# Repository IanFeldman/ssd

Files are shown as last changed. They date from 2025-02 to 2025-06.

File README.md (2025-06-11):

# ssd
2025 Cal Poly EE/CPE senior project exploring nonvolatile flash storage. Includes a [prototype design](#nor-prototype-2) using an 8051 and small NOR flash IC and the [final design](#nand-final) with a modern Atmel microcontroller and multiple high-density NAND flash ICs on a custom PCB.

## nand-final
2Gib NAND flash memory board with virtual serial interface over USB. Supports default and RAID 1 configurations.

### Firmware Build and Flash Instructions (Linux)
```sh
# Install dependencies
sudo apt install gcc-avr avr-libc avrdude make

# Clone this repo
git clone https://github.com/IanFeldman/ssd.git
cd ssd/nand-final/firmware

# Burn fuses (first time only)
make fuses

# Compile and flash firmware using ISP
# (edit makefile as needed)
make [UART=1] [RAID=1] # Optionally enable UART debugging or RAID 1
make flash
```

UART debugging interferes with some NAND chip control lines. Enable it at your own risk.\
RAID is performed across all 4 chips, so it decreases the address space fourfold.

### Usage:
Plug PCB into PC USB port and open a terminal with:\
```screen /dev/[path-to-usb-device] -b 9600```

### Commands:
<table>

<tr>
<td>Command</td>
<td>Usage</td>
<td>Function</td>
</tr>
<tr>
<td>Help</td>
<td>
  
```help```
</td>
<td>Displays device info and a list of commands.</td>
</tr>
<tr>
<td>Read</td>
<td>
  
```read 0x[row] 0x[column] [size]```
</td>
<td>Reads [size] bytes from memory.<br>A device will not read across a page boundary.</td>
</tr>
<tr>
<td>Write</td>
<td>
  
```write 0x[row] 0x[column] 0x[data]```
</td>
<td>Writes a single byte [data] to memory.</td>
</tr>
<tr>
<td>Erase</td>
<td>
  
```erase 0x[row]```
</td>
<td>Erases a block from memory.</td>
</tr>
</table>

Note:
- ```[row]``` is three bytes and represents a page address. Max value: 0x0FFFFF (0x040000 with RAID enabled).
- ```[column]``` is two bytes and represents a page offset in bytes. Max value: 0x07FF.
- ```[data]``` is one byte.
- ```[size]``` is a decimal unsigned integer.

## nor-prototype-2
Prototype breadboard 512kB flash memory storage device. Interface over UART at 9600 baud. Compile with SDCC and program with avrdude. See hardware schematic for hardware details.

### Firmware Build and Flash Instructions (Linux)
```sh
# Install dependencies
sudo apt install sdcc

# Clone this repo
git clone https://github.com/IanFeldman/ssd.git
cd ssd/nor-prototype-2/firmware

# Compile and flash firmware using ISP
make
./program.sh
```

### Usage:
Connect a serial cable to ```RXD``` and ```TXD``` on the microcontroller. Open a terminal with:\
```screen /dev/[path-to-serial-cable] -b 9600```

### Commands:
- Read an address ```r[address]```
- Erase an address ```e[address]```
- Program an address ```p[address][data]```

Where:
- ```[address]``` is 3 hex bytes
- ```[data]``` is one hex byte

## nor-prototype-1
Flash memory controller prototype.

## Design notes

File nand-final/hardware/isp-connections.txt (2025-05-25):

PCB | Arduino ISP
----+------------
GND | GND
PC1 | 10 (RESET)
PB2 | 11 (MOSI)
PB1 | 13 (SCLK)
3V3 | 3V3
PB3 | 12 (MISO)

PCB | SERIAL
----+-------
PD3 | RX (right)
PD2 | TX (left)

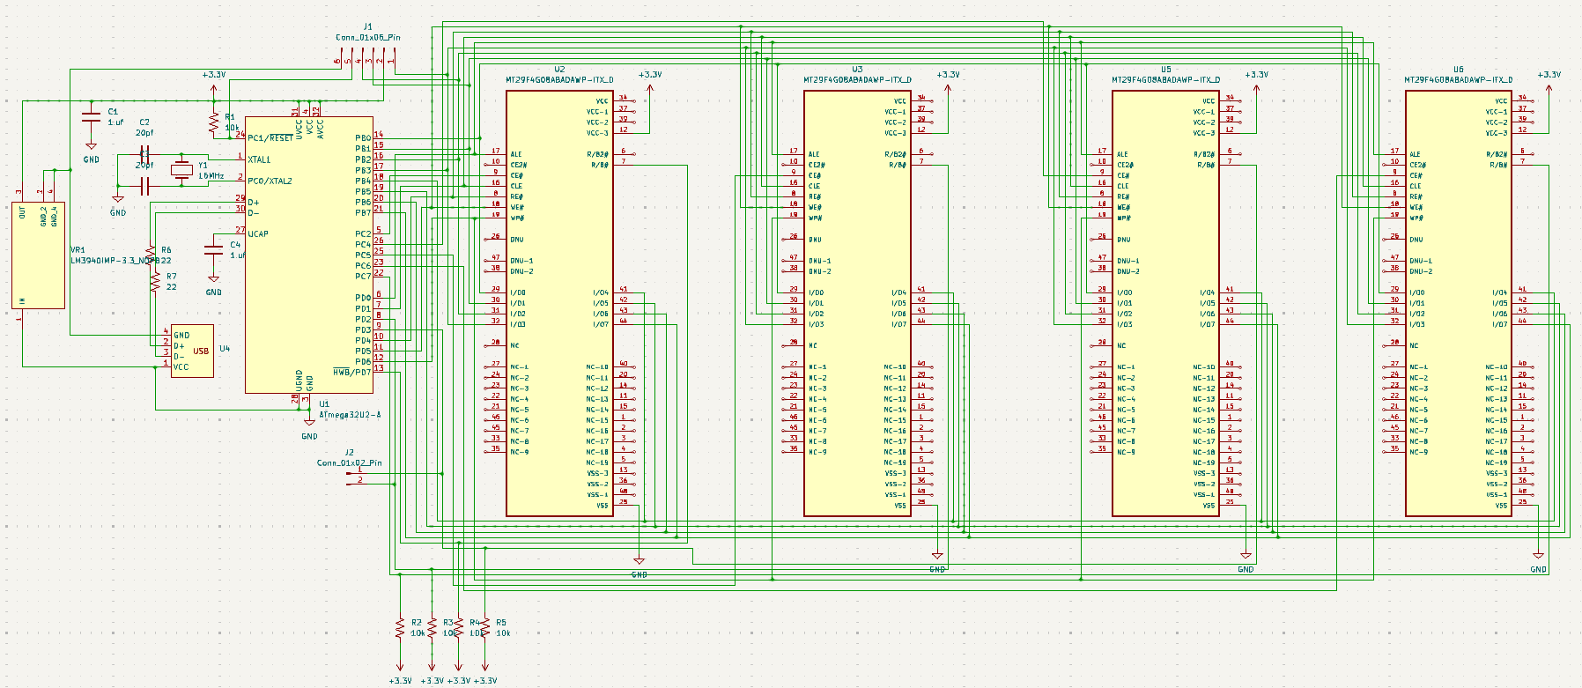
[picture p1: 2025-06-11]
nand-final/hardware/schematic.png

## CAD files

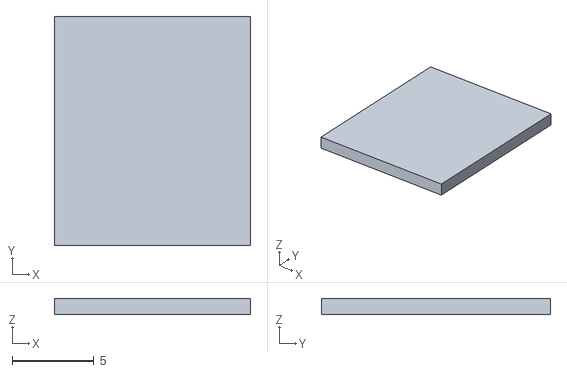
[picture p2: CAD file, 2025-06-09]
nand-final/3d-models/usb-plate-1mm.stl
12.0 x 14.0 x 1.00

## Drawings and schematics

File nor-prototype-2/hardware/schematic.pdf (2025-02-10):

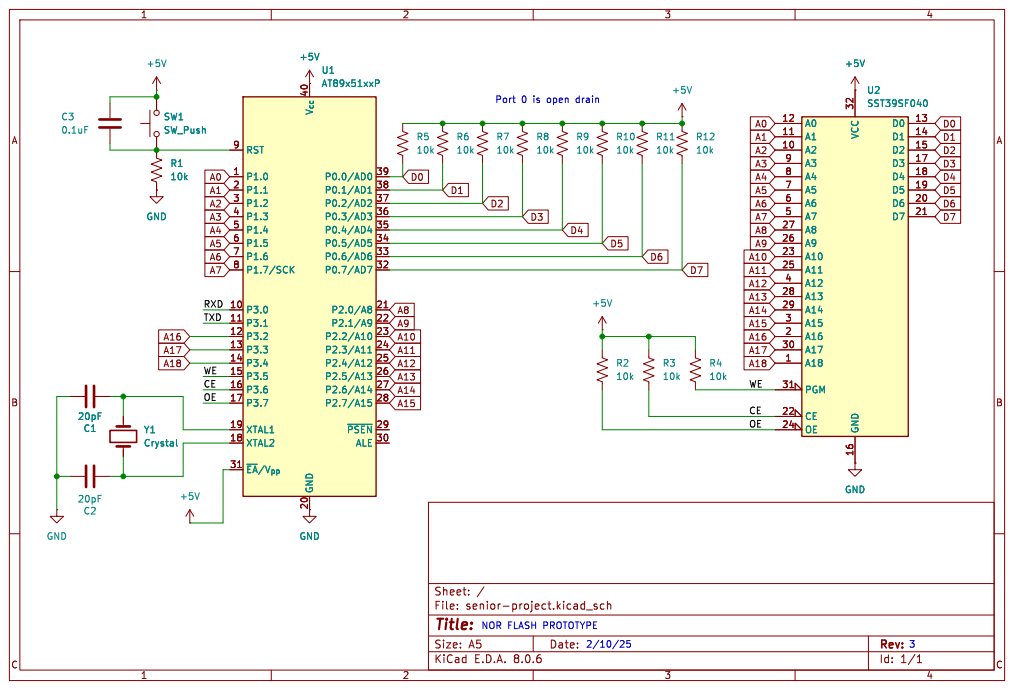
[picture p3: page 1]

Port 0 is open drain NOR FLASH PROTOTYPE

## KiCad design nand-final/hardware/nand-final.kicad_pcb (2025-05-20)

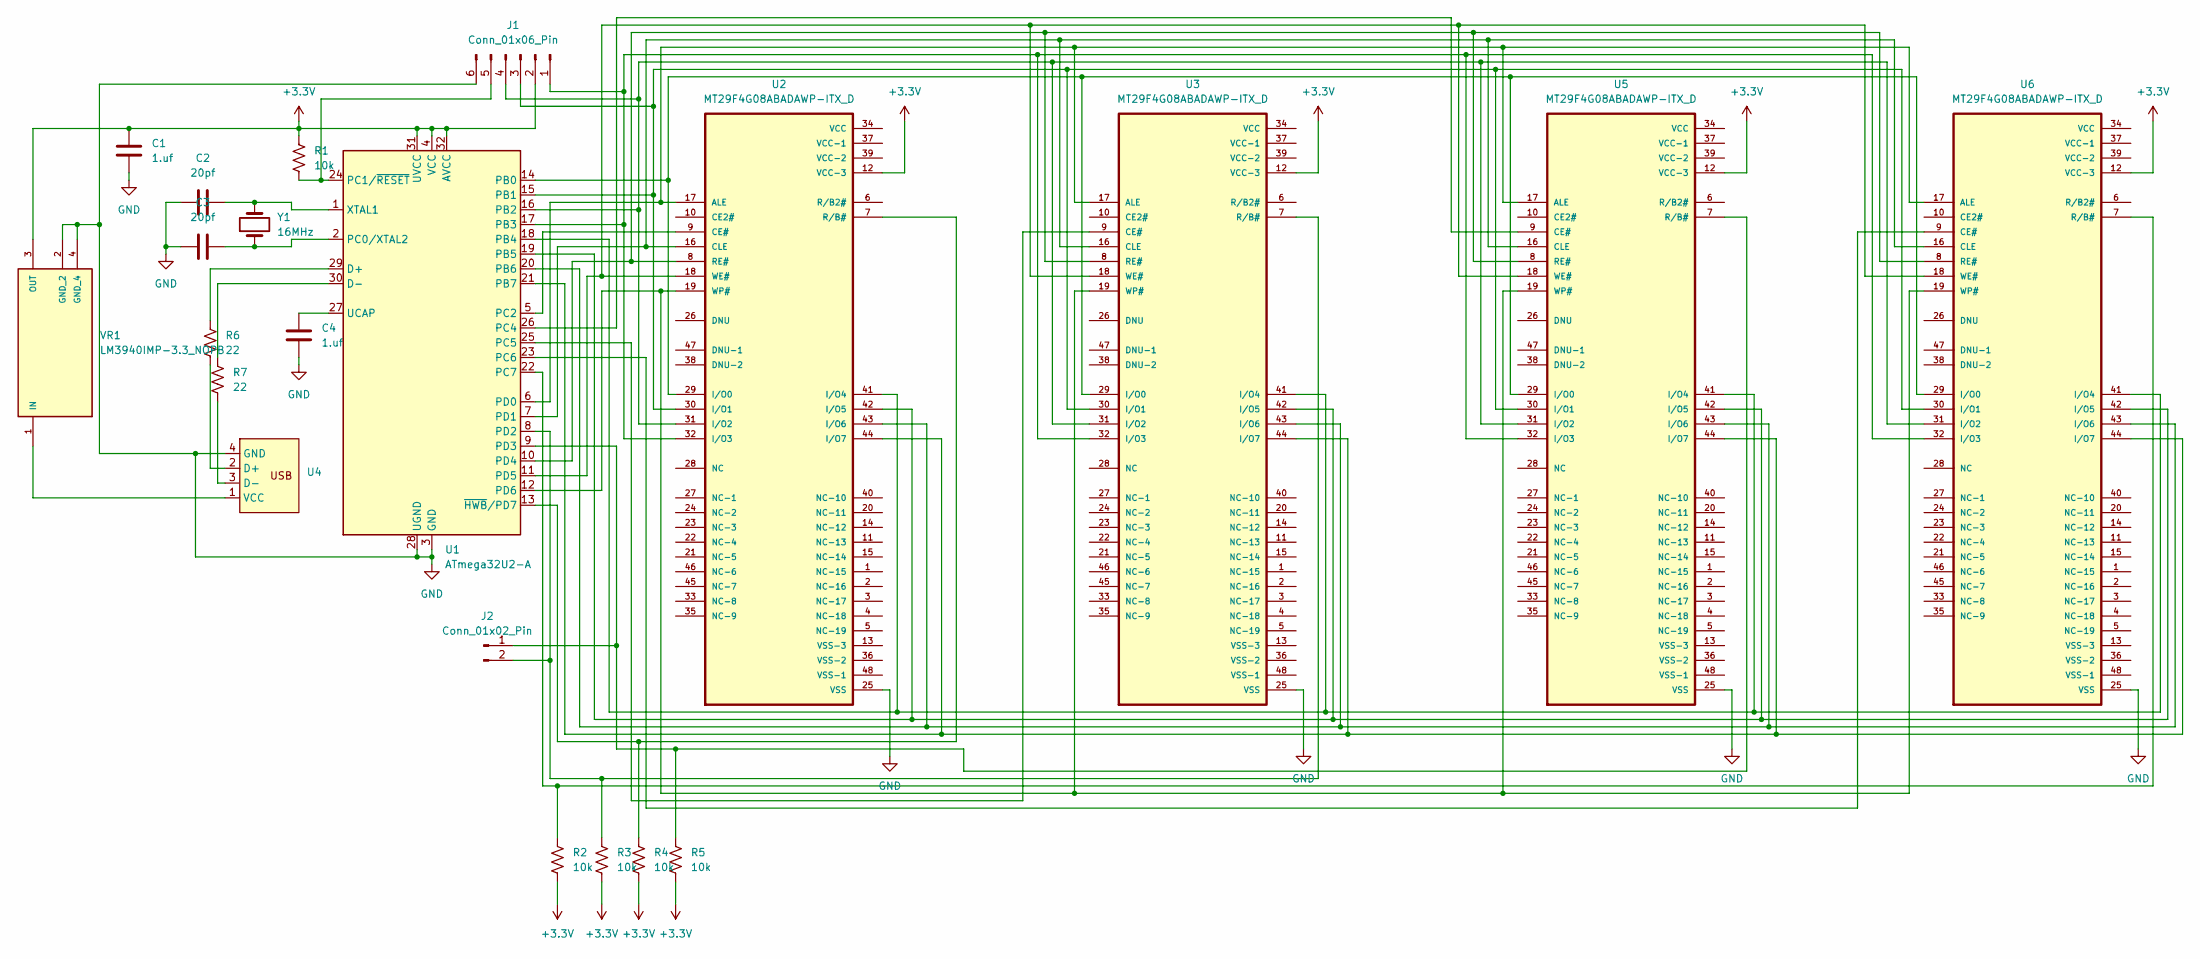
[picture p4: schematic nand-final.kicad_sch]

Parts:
C1, C4: 1.uf; C_0805_2012Metric_Pad1.18x1.45mm_HandSolder
C2, C3: 20pf; C_0805_2012Metric_Pad1.18x1.45mm_HandSolder
J1: Conn_01x06_Pin; PinHeader_1x06_P2.54mm_Vertical
J2: Conn_01x02_Pin; PinHeader_1x02_P2.54mm_Vertical
R1, R2, R3, R4, R5: 10k; R_0805_2012Metric_Pad1.20x1.40mm_HandSolder
R6, R7: 22; R_0805_2012Metric_Pad1.20x1.40mm_HandSolder
U1: ATmega32U2-A; TQFP-32_7x7mm_P0.8mm
U2, U3, U5, U6: MT29F4G08ABADAWP-ITX_D; TSOP-I-48_18.4x12mm_P0.5mm
U4: PCB_USB_connector
VR1: LM3940IMP-3.3_NOPB; SOT-223; PARTREV G
Y1: 16MHz; Crystal_HC49-U_Vertical

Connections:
+3.3V: C1.2, J1.2, R1.1, R2.2, R3.2, R4.2, R5.2, U1.4 (VCC), U1.31 (UVCC), U1.32 (AVCC), U2.12 (VCC-3), U3.12 (VCC-3), U5.12 (VCC-3), U6.12 (VCC-3), VR1.3 (OUT)
GND: C1.1, C2.2, C3.2, C4.1, J1.6, U1.3 (GND), U1.28 (UGND), U2.25 (VSS), U3.25 (VSS), U4.4 (GND), U5.25 (VSS), U6.25 (VSS), VR1.2 (GND_2), VR1.4 (GND_4)
unnamed: J1.1, U1.17 (PB3), U2.32 (I/O3), U3.32 (I/O3), U5.32 (I/O3), U6.32 (I/O3)
unnamed: J1.3, U1.15 (PB1), U2.30 (I/O1), U3.30 (I/O1), U5.30 (I/O1), U6.30 (I/O1)
unnamed: J1.4, U1.16 (PB2), U2.31 (I/O2), U3.31 (I/O2), U5.31 (I/O2), U6.31 (I/O2)
unnamed: J1.5, R1.2, U1.24 (PC1/~RESET)
unnamed: J2.1, R5.1, U1.9 (PD3), U5.7 (R/B#)
unnamed: J2.2, R3.1, U1.8 (PD2), U3.7 (R/B#)
unnamed: R6.1, U1.29 (D+)
unnamed: R7.1, U1.30 (D-)
unnamed: U1.14 (PB0), U2.29 (I/O0), U3.29 (I/O0), U5.29 (I/O0), U6.29 (I/O0)
unnamed: U1.18 (PB4), U2.41 (I/O4), U3.41 (I/O4), U5.41 (I/O4), U6.41 (I/O4)
unnamed: U1.19 (PB5), U2.42 (I/O5), U3.42 (I/O5), U5.42 (I/O5), U6.42 (I/O5)
unnamed: U1.20 (PB6), U2.43 (I/O6), U3.43 (I/O6), U5.43 (I/O6), U6.43 (I/O6)
unnamed: U1.21 (PB7), U2.44 (I/O7), U3.44 (I/O7), U5.44 (I/O7), U6.44 (I/O7)
unnamed: C3.1, U1.2 (PC0/XTAL2), Y1.1
unnamed: U1.5 (PC2), U2.9 (CE#)
unnamed: U1.26 (PC4), U5.9 (CE#)
unnamed: U1.25 (PC5), U3.9 (CE#)
unnamed: U1.23 (PC6), U6.9 (CE#)
unnamed: R2.1, U1.22 (PC7), U6.7 (R/B#)
unnamed: U1.6 (PD0), U2.17 (ALE), U3.17 (ALE), U5.17 (ALE), U6.17 (ALE)
unnamed: U1.7 (PD1), U2.16 (CLE), U3.16 (CLE), U5.16 (CLE), U6.16 (CLE)
unnamed: U1.10 (PD4), U2.8 (RE#), U3.8 (RE#), U5.8 (RE#), U6.8 (RE#)
unnamed: U1.11 (PD5), U2.18 (WE#), U3.18 (WE#), U5.18 (WE#), U6.18 (WE#)
unnamed: U1.12 (PD6), U2.19 (WP#), U3.19 (WP#), U5.19 (WP#), U6.19 (WP#)
unnamed: C4.2, U1.27 (UCAP)
unnamed: C2.1, U1.1 (XTAL1), Y1.2
unnamed: R4.1, U1.13 (~HWB/PD7), U2.7 (R/B#)
unnamed: R6.2, U4.2 (D+)
unnamed: R7.2, U4.3 (D-)
unnamed: U4.1 (VCC), VR1.1 (IN)

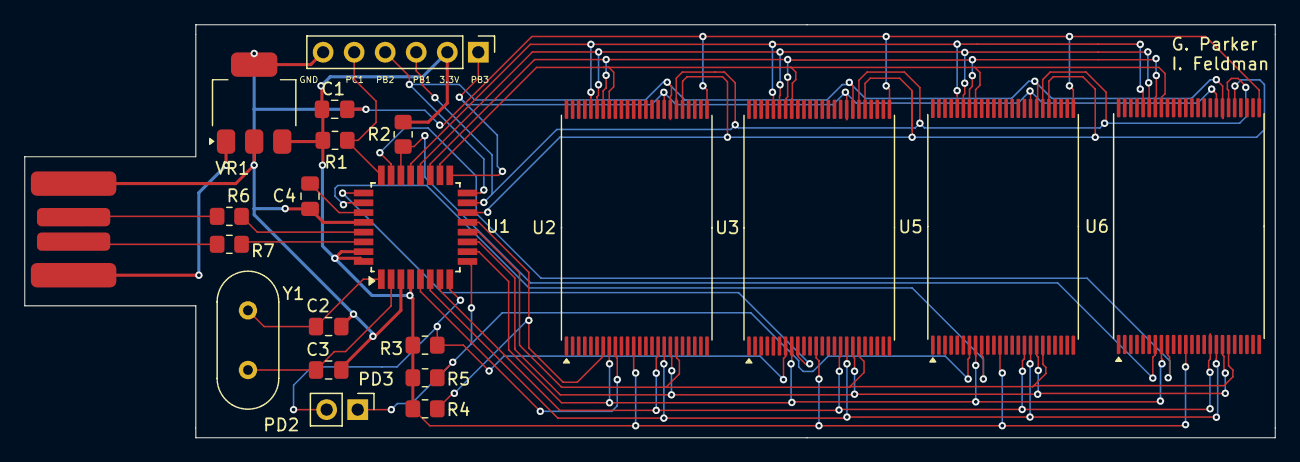
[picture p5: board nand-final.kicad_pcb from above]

Board: 2 copper layers, 102.3 x 33.8 mm, 21 parts (0 on the bottom side), 32 nets.

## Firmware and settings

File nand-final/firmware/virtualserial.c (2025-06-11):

/*
             LUFA Library
     Copyright (C) Dean Camera, 2021.

  dean [at] fourwalledcubicle [dot] com
           www.lufa-lib.org
*/

/*
  Copyright 2021  Dean Camera (dean [at] fourwalledcubicle [dot] com)

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
  The author disclaims all warranties with regard to this
  software, including all implied warranties of merchantability
  and fitness.  In no event shall the author be liable for any
  special, indirect or consequential damages or any damages
  whatsoever resulting from loss of use, data or profits, whether
  in an action of contract, negligence or other tortious action,
  arising out of or in connection with the use or performance of
  this software.
*/

/*
 * Edited by Ian Feldman and Grayson Parker
 * June 2025
 */

#include <stdlib.h>
#include "virtualserial.h"
#include "lib/flash.h"
#include "lib/test.h"
#include "lib/uart.h"
#include "lib/util.h"

/** LUFA CDC Class driver interface configuration and state information. This structure is
 *  passed to all CDC Class driver functions, so that multiple instances of the same class
 *  within a device can be differentiated from one another.
 */
USB_ClassInfo_CDC_Device_t VirtualSerial_CDC_Interface =
    {
        .Config =
            {
                .ControlInterfaceNumber   = INTERFACE_ID_CDC_CCI,
                .DataINEndpoint           =
                    {
                        .Address          = CDC_TX_EPADDR,
                        .Size             = CDC_TXRX_EPSIZE,
                        .Banks            = 1,
                    },
                .DataOUTEndpoint =
                    {
                        .Address          = CDC_RX_EPADDR,
                        .Size             = CDC_TXRX_EPSIZE,
                        .Banks            = 1,
                    },
                .NotificationEndpoint =
                    {
                        .Address          = CDC_NOTIFICATION_EPADDR,
                        .Size             = CDC_NOTIFICATION_EPSIZE,
                        .Banks            = 1,
                    },
            },
    };

/** Standard file stream for the CDC interface when set up, so that the virtual CDC COM port can be
 *  used like any regular character stream in the C APIs.
 */
static FILE USBSerialStream;


/** Main program entry point. This routine contains the overall program flow, including initial
 *  setup of all components and the main program loop.
 */
int main(void)
{
    SetupHardware();

    /* Create a regular character stream for the interface so that it can be used with the stdio.h functions */
    CDC_Device_CreateStream(&VirtualSerial_CDC_Interface, &USBSerialStream);

    GlobalInterruptEnable();

    for (;;)
    {
        Poll();
        CDC_Device_USBTask(&VirtualSerial_CDC_Interface);
        USB_USBTask();
    }
}


/** Configures the board hardware and chip peripherals for the demo's functionality. */
void SetupHardware(void)
{
    /* Disable watchdog if enabled by bootloader/fuses */
    MCUSR &= ~(1 << WDRF);
    wdt_disable();

    /* Disable clock division */
    clock_prescale_set(clock_div_1);

    /* Hardware Initialization */
    #ifdef UART
    uart_init();
    uart_print_esc(CLEAR_SCREEN);
    uart_print_esc(HOME_CURSOR);
    #endif
    flash_init();
    USB_Init();

    /* Clear virtual serial */
    SendEsc(CLEAR_SCREEN);
    SendEsc(HOME_CURSOR);
    SendPrefix();
}


/* Poll for user input. */
void Poll(void)
{
    static char command_buffer[CMD_BUFFER_SIZE];
    static int i = 0;

    int16_t received_byte = CDC_Device_ReceiveByte(&VirtualSerial_CDC_Interface);
    if (received_byte >= 0)
    {
        char ch = (char)received_byte;

        /* submit line */
        if (ch == '\n' || ch == '\r' || i == CMD_BUFFER_SIZE - 1)
        {
            command_buffer[i] = '\0';
            ProcessLine(command_buffer, i);
            CDC_Device_Flush(&VirtualSerial_CDC_Interface);
            i = 0;
            return;
        }
        /* backspace */
        if ((ch == '\b' || ch  == 127))
        {
            if (i > 0)
            {
                SendEsc(RETREAT_CURSOR);
                CDC_Device_SendByte(&VirtualSerial_CDC_Interface, ' ');
                SendEsc(RETREAT_CURSOR);
                i--;
            }
            return;
        }
        /* disregard ansi escapes */
        if (ch == ESC_CHAR)
        {
            return;
        }
        /* save to buffer and echo back */
        command_buffer[i++] = ch;
        CDC_Device_SendByte(&VirtualSerial_CDC_Interface, ch);
    }
}


/* Process input string. */
void ProcessLine(char *buffer, int size)
{
    SendEsc(NEW_LINE);

    /* split line by spaces */
    char *token = strtok(buffer, " ");
    if (token != NULL)
    {
        /* usage: clear */
        if (!strcmp(token, CLEAR_CMD_STR))
        {
            CDC_Device_Flush(&VirtualSerial_CDC_Interface);
            SendEsc(CLEAR_SCREEN);
            SendEsc(HOME_CURSOR);
            SendPrefix();
            return;
        }
        /* usage: help */
        else if (!strcmp(token, HELP_CMD_STR))
        {
            ProcessHelp();
        }
        else if (!strcmp(token, READ_CMD_STR))
        {
            ProcessRead();
        }
        else if (!strcmp(token, WRITE_CMD_STR))
        {
            ProcessWrite();
        }
        else if (!strcmp(token, ERASE_CMD_STR))
        {
            ProcessErase();
        }
        else
        {
            CDC_Device_SendString(&VirtualSerial_CDC_Interface, "Unknown command");
            SendEsc(NEW_LINE);
        }
    }
    SendPrefix();
}


/* Process help command. */
void ProcessHelp(void)
{
    /* raid info */
    #ifdef RAID
    CDC_Device_SendString(&VirtualSerial_CDC_Interface,
        "RAID 1 enabled");
    SendEsc(NEW_LINE);
    #else
    CDC_Device_SendString(&VirtualSerial_CDC_Interface,
        "RAID 1 disabled");
    SendEsc(NEW_LINE);
    #endif

    /* uart info */
    #ifdef UART
    CDC_Device_SendString(&VirtualSerial_CDC_Interface,
        "UART enabled");
    SendEsc(NEW_LINE);
    #else
    CDC_Device_SendString(&VirtualSerial_CDC_Interface,
        "UART disabled");
    SendEsc(NEW_LINE);
    #endif

    CDC_Device_SendString(&VirtualSerial_CDC_Interface,
        "READ");
    SendEsc(NEW_LINE);
    CDC_Device_SendString(&VirtualSerial_CDC_Interface,
        "  usage: read [row] [column] [size]");
    SendEsc(NEW_LINE);
    CDC_Device_SendString(&VirtualSerial_CDC_Interface,
        "WRITE");
    SendEsc(NEW_LINE);
    CDC_Device_SendString(&VirtualSerial_CDC_Interface,
        "  usage: write [row] [column] [data]");
    SendEsc(NEW_LINE);
    CDC_Device_SendString(&VirtualSerial_CDC_Interface,
        "ERASE");
    SendEsc(NEW_LINE);
    CDC_Device_SendString(&VirtualSerial_CDC_Interface,
        "  usage: erase [row]");
    SendEsc(NEW_LINE);
}


/* Process read command.
 * usage: read row col size
 */
void ProcessRead(void)
{
    #ifdef RAID
    static int chip_id = 1;
    #endif
    char *row_str = strtok(NULL, " ");
    char *col_str = strtok(NULL, " ");
    char *siz_str = strtok(NULL, " ");
    /* check data is valid */
    if (!row_str || !col_str || !siz_str)
    {
        CDC_Device_SendString(&VirtualSerial_CDC_Interface, "Invalid command");
        SendEsc(NEW_LINE);
        return;
    }
    if ((strlen(row_str) != ROW_STR_LEN) || (strlen(col_str) != COL_STR_LEN))
    {
        CDC_Device_SendString(&VirtualSerial_CDC_Interface, "Invalid parameter lengths");
        SendEsc(NEW_LINE);
        return;
    }
    if (CheckHexPrefix(row_str) || CheckHexPrefix(col_str))
    {
        CDC_Device_SendString(&VirtualSerial_CDC_Interface, "Invalid format");
        SendEsc(NEW_LINE);
        return;
    }

    uint32_t row = hex_str_to_int(row_str, 6);
    uint16_t col = hex_str_to_int(col_str, 4);
    uint16_t siz = (uint16_t)atoi(siz_str);

    /* check if address out of bounds */
    if (row >= ROW_MAX || col >= COL_MAX)
    {
        CDC_Device_SendString(&VirtualSerial_CDC_Interface, "Address out of bounds");
        SendEsc(NEW_LINE);
        return;
    }

    /* determine size */
    int max_size = COL_MAX - col;
    if (siz > max_size)
    {
        CDC_Device_SendString(&VirtualSerial_CDC_Interface, "Reading only to page boundary");
        SendEsc(NEW_LINE);
        siz = max_size;
    }

    #ifdef RAID
    uint32_t chip_row = row;
    #else
    /* divide by (64 * 4096) */
    uint32_t chip = row >> 18;
    uint32_t chip_row = row - (chip << 18);
    int chip_id = chip + 1;
    #endif

    /* keep usb alive */
    USB_USBTask();

    /* flash_pulse_debug(); */

    /* read data */
    uint8_t data[MAX_READ_SIZE];
    char byte[4] = { '\0', '\0', ' ', '\0' };
    int curr_width = 0;
    flash_enable(chip_id);
    /* do it in multiple batches if necessary */
    int bytes_read = 0;
    while (bytes_read < siz)
    {
        /* read */
        int bytes_to_read = min(siz - bytes_read, MAX_READ_SIZE);
        flash_read_batch(chip_row, col + bytes_read, chip_id, bytes_to_read, data);

        /* print */
        for (int i = 0; i < bytes_to_read; i++)
        {
            byte_to_hex_str(data[i], byte);
            CDC_Device_SendString(&VirtualSerial_CDC_Interface, byte);
            curr_width += 3; /* write three characters for each byte */
            if (curr_width >= TERMINAL_WIDTH)
            {
                SendEsc(NEW_LINE);
                curr_width = 0;
            }
        }

        bytes_read += bytes_to_read;
    }
    flash_disable(chip_id);

    /* flash_pulse_debug(); */

    SendEsc(NEW_LINE);

    #ifdef RAID
    /* move on to next chip */
    chip_id++;
    if (chip_id > CHIP_COUNT)
    {
        chip_id = 1;
    }
    #endif
}


/* Process write command.
 * usage: write row col data
 */
void ProcessWrite(void)
{
    char *row_str = strtok(NULL, " ");
    char *col_str = strtok(NULL, " ");
    char *dat_str = strtok(NULL, " ");
    /* check data is valid */
    if (!row_str || !col_str || !dat_str)
    {
        CDC_Device_SendString(&VirtualSerial_CDC_Interface, "Invalid command");
        SendEsc(NEW_LINE);
        return;
    }
    if ((strlen(row_str) != ROW_STR_LEN) || (strlen(col_str) != COL_STR_LEN) ||
       (strlen(dat_str) != DATA_STR_LEN))
    {
        CDC_Device_SendString(&VirtualSerial_CDC_Interface, "Invalid parameter lengths");
        SendEsc(NEW_LINE);
        return;
    }
    if (CheckHexPrefix(row_str) || CheckHexPrefix(col_str) || CheckHexPrefix(dat_str))
    {
        CDC_Device_SendString(&VirtualSerial_CDC_Interface, "Invalid format");
        SendEsc(NEW_LINE);
        return;
    }

    uint32_t row = hex_str_to_int(row_str, 6);
    uint16_t col = hex_str_to_int(col_str, 4);
    uint8_t  dat = hex_str_to_int(dat_str, 2);

    /* check if address out of bounds */
    if (row >= ROW_MAX || col >= COL_MAX)
    {
        CDC_Device_SendString(&VirtualSerial_CDC_Interface, "Address out of bounds");
        SendEsc(NEW_LINE);
        return;
    }

    /* keep usb alive */
    USB_USBTask();

    /* flash_pulse_debug(); */

    #ifdef RAID
    /* write data to all chips */
    for (int chip_id = 1; chip_id <= CHIP_COUNT; chip_id++)
    {
        flash_enable(chip_id);
        flash_program(row, col, &dat, 1, chip_id);
        flash_disable(chip_id);
    }
    #else
    /* write data to single chip */
    /* divide by (64 * 4096) */
    uint32_t chip = row >> 18;
    uint32_t chip_row = row - (chip << 18);
    int chip_id = chip + 1;
    flash_enable(chip_id);
    flash_program(chip_row, col, &dat, 1, chip_id);
    flash_disable(chip_id);
    #endif

    /* flash_pulse_debug(); */
}


/* Process erase command.
 * usage: erase row
 */
void ProcessErase(void)
{
    char *row_str = strtok(NULL, " ");
    /* check data is valid */
    if (!row_str)
    {
        CDC_Device_SendString(&VirtualSerial_CDC_Interface, "Invalid command");
        SendEsc(NEW_LINE);
        return;
    }
    if (strlen(row_str) != ROW_STR_LEN)
    {
        CDC_Device_SendString(&VirtualSerial_CDC_Interface, "Invalid parameter length");
        SendEsc(NEW_LINE);
        return;
    }
    if (CheckHexPrefix(row_str))
    {
        CDC_Device_SendString(&VirtualSerial_CDC_Interface, "Invalid format");
        SendEsc(NEW_LINE);
        return;
    }

    /* check if address out of bounds */
    uint32_t row = hex_str_to_int(row_str, 6);
    if (row >= ROW_MAX)
    {
        CDC_Device_SendString(&VirtualSerial_CDC_Interface, "Address out of bounds");
        SendEsc(NEW_LINE);
        return;
    }

    /* keep usb alive */
    USB_USBTask();

    /* flash_pulse_debug(); */

    #ifdef RAID
    /* erase on all chips */
    for (int chip_id = 1; chip_id <= CHIP_COUNT; chip_id++)
    {
        flash_enable(chip_id);
        flash_erase(row, chip_id);
        flash_disable(chip_id);
    }
    #else
    /* erase on single chip */
    /* divide by (64 * 4096) */
    uint32_t chip = row >> 18;
    uint32_t chip_row = row - (chip << 18);
    int chip_id = chip + 1;
    flash_enable(chip_id);
    flash_erase(chip_row, chip_id);
    flash_disable(chip_id);
    #endif

    /* flash_pulse_debug(); */
}


/* Return 0 if string has 0x or 0X at start, 1 if not */
int CheckHexPrefix(char *str)
{
    if (!str)
    {
        return 1;
    }
    int first = (str[0] == '0');
    int second = (str[1] == 'X' || str[1] == 'x');
    return !(first && second);
}


/* Send ANSI escape sequence */
void SendEsc(char *sequence)
{
    CDC_Device_SendByte(&VirtualSerial_CDC_Interface, ESC_CHAR);
    CDC_Device_SendString(&VirtualSerial_CDC_Interface, sequence);
}


/* Send '>' character. */
void SendPrefix(void)
{
    CDC_Device_SendString(&VirtualSerial_CDC_Interface, PREFIX);
}


/* Event handler for the library USB Connection event. */
void EVENT_USB_Device_Connect(void)
{
    #ifdef UART
    uart_print_ln("USB Connect");
    #endif
}


/* Event handler for the library USB Disconnection event. */
void EVENT_USB_Device_Disconnect(void)
{
    #ifdef UART
    uart_print_ln("USB Disconnect");
    #endif
}


/* Event handler for the library USB Configuration Changed event. */
void EVENT_USB_Device_ConfigurationChanged(void)
{
    #ifdef UART
    uart_print_ln("USB Config Changed");
    #endif

    bool ConfigSuccess = true;

    ConfigSuccess &= CDC_Device_ConfigureEndpoints(&VirtualSerial_CDC_Interface);
}


/* Event handler for the library USB Control Request reception event. */
void EVENT_USB_Device_ControlRequest(void)
{
    CDC_Device_ProcessControlRequest(&VirtualSerial_CDC_Interface);
}


/*  CDC class driver callback function the processing of changes to the virtual
 *  control lines sent from the host..
 *
 *  \param[in] CDCInterfaceInfo  Pointer to the CDC class interface configuration structure being referenced
 */
void EVENT_CDC_Device_ControLineStateChanged(USB_ClassInfo_CDC_Device_t *const CDCInterfaceInfo)
{
    /* You can get changes to the virtual CDC lines in this callback; a common
       use-case is to use the Data Terminal Ready (DTR) flag to enable and
       disable CDC communications in your application when set to avoid the
       application blocking while waiting for a host to become ready and read
       in the pending data from the USB endpoints.
    */
    bool HostReady = (CDCInterfaceInfo->State.ControlLineStates.HostToDevice & CDC_CONTROL_LINE_OUT_DTR) != 0;

    (void)HostReady;
}

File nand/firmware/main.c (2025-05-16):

#include "flash.h"
#include "uart.h"

int main()
{
    /* configure uart */
    uart_init();
    uart_print_esc(CLEAR_SCREEN);
    uart_print_esc(HOME_CURSOR);
    uart_print_nl("UART initialized");

    /* configure flash */
    flash_init();
    uart_print_nl("Flash initialized");

    for (int chip = 1; chip <= 4; chip++)
    {
        uart_print_esc(NEW_LINE);
        uart_print("Testing chip: ");
        uart_print_hex(chip);
        uart_print_esc(NEW_LINE);

        flash_enable(chip);

        /* read id */
        uint8_t id[5] = {0, 0, 0, 0, 0};
        flash_read_id(id, chip);
        uart_print("Flash ID: ");
        for (int i = 0; i < 5; i++)
        {
            uart_print_hex(id[i]);
            uart_print(" ");
        }
        uart_print_esc(NEW_LINE);

        /* set address */
        uint32_t row = 0x00000028;
        uint16_t column = 0x0013;
        uart_print("At address ");
        uart_print_address(row, column);

        /* read byte */
        uint8_t data = flash_read(row, column, chip);
        uart_print("Read data: ");
        uart_print_hex(data);
        uart_print_esc(NEW_LINE);

        /* erase byte */
        flash_erase(row, chip);
        uart_print_nl("Erased block");

        /* reread byte */
        data = flash_read(row, column, chip);
        uart_print("Read data: ");
        uart_print_hex(data);
        uart_print_esc(NEW_LINE);

        /* program byte */
        data = 0xB6;
        flash_program(row, column, &data, sizeof(data), chip);
        uart_print("Wrote data: ");
        uart_print_hex(data);
        uart_print_esc(NEW_LINE);

        /* reread byte */
        data = flash_read(row, column, chip);
        uart_print("Read data: ");
        uart_print_hex(data);
        uart_print_esc(NEW_LINE);

        flash_disable(chip);
    }
    return 0;
}

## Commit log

2025-02-05 Create Makefile, clean uart init
2025-02-05 Create print function
2025-02-05 Add hardware schematic
2025-02-06 Support ANSI escape codes, refactor uart code
2025-02-06 Fix uart print error handling
    [main.c, uart.c]
2025-02-09 Get data from serial interrupts
2025-02-09 Fix control pins, create get_id()
    [main.c]
2025-02-10 Fix set_address(), delete useless code
    [main.c]
2025-02-10 Update schematic with pull ups for port 0
2025-02-10 Remove random line from schematic
2025-02-14 Optimize memory overhead of uart
2025-02-18 Add print address function
2025-02-18 Cap print address function at max address
2025-02-18 Fix handle unknown input
    [main.c]
2025-02-24 Change crystal capacitors
2025-02-28 Take device measurements
2025-03-17 Add uart
2025-03-17 Configure uart for hello world
2025-03-17 Update schematic
2025-05-15 Fix fuses
2025-05-15 Print new line
2025-05-20 Replace led debug with uart debug
    [MassStorage.c]
2025-05-20 Rename to lower case
2025-05-20 Add hardware
    [nand-final.kicad_pcb, nand-final.kicad_sch]
2025-05-20 Remove old schematic
2025-06-09 Add 3d model
    [usb-plate-1mm.stl]
2025-06-10 Shorten help, convert to 0x inputs
    [virtualserial.c]
2025-06-11 Add uart define
2025-06-11 Add debug timing pin
2025-06-11 Upload nor prototype
2025-06-11 Add schematic images
2025-06-11 Rename folders
    [nand-final.kicad_pcb, nand-final.kicad_sch, usb-plate-1mm.stl]
